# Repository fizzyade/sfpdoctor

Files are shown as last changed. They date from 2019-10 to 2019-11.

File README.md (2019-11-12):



[uri_license]: https://www.gnu.org/licenses/gpl-3.0.en.html
[uri_license_image]: https://img.shields.io/badge/License-GPLv3-blue.svg

[][uri_license]

# SFP Doctor
SFP Doctor is an open source hardware &amp; software project for reading and writing the EEPROM inside SFP &amp; SFP+ modules.

## About

SFP modules contain an EEPROM which contains information about the module.  This information includes the OUI (Organizationally Unique Identifier) which identifies the vendor of the module.

Some NIC's and switches are locked to using a particular vendors own SFP modules, this hardware and software project provides a tool for reading and modifying this information (providing the vendor has not disabled write access to the EEPROM).

The hardware design is intended to be as simple and cheap as possible, therefore it makes use of the [Cypress CYC8CKIT-059](https://www.cypress.com/documentation/development-kitsboards/cy8ckit-059-psoc-5lp-prototyping-kit-onboard-programmer-and) prototyping board as the USB interface to the EEPROM on the module, this board is readily and cheaply available.

## Repository Contents

* **/hardware** - [KiCad](http://kicad-pcb.org/) schematic and PCB layout source files.
* **/firmware** - The firmware for the [CY8C5888LTI-LP097](https://www.cypress.com/part/cy8c5888lti-lp097) microcontroller on the [Cypress CYC8CKIT-059](https://www.cypress.com/documentation/development-kitsboards/cy8ckit-059-psoc-5lp-prototyping-kit-onboard-programmer-and) prototyping board.
* **/software** - The desktop software to control the hardware.
* **/drivers** - Platform dependent drivers for the hardware interface.

Development takes place in the develop branch, master is currently a placeholder and not up to date.

## Required Tools

* **[Cypress PSoC Creator](https://www.cypress.com/products/psoc-creator-integrated-design-environment-ide)** for firmware development.
* **[KiCad](http://kicad-pcb.org/)** for hardware design.
* **[Node.js](https://nodejs.org/)** for desktop software.
* **[Yarn](https://yarnpkg.com/)** for desktop software.
* **[ELECTRON](https://electronjs.org/)** for desktop software development.

## Building Software

### Desktop

After installing the prequestite packages, use the following commands.

    yarn run build
    yarn run start

The platform binary can be created with the following commands.

    yarn run build
    yarn run dist

(*Please note that currently the software is not functional*)

### Firmware

Open the firmware project in PSOC Creator and select build to create the firmware image.

## Project Status

### Hardware

* **Design:** Complete.
* **Manufacture:** Complete.
    * _**07 Nov 2019**_ - Board Assembled, ready for test.
    * _**10 Nov 2019**_ - Board tested and working.

Bare BoardComplete Board

(_please **NOTE:** in this picture the CY8CKIT-059 module is installed the wrong way around, picture to be updated soon.)_

Render Rev. 1.3

(_Render of Rev. 1.3 board_)

### Firmware

* **Development:** Started.

### Software

* **Development:** Started.

## With Thanks

This project is using a USB VID & PID kindly allocated by [pid.codes](http://pid.codes).  Their repository can be found [here](https://github.com/pidcodes/pidcodes.github.com).  They support open source development by providing VID/PID pairs for free.

## License

This project is open source and the entire project is released under the [GPLv3 license](https://www.gnu.org/licenses/gpl-3.0.en.html).

Distributed as-is; no warranty is given.

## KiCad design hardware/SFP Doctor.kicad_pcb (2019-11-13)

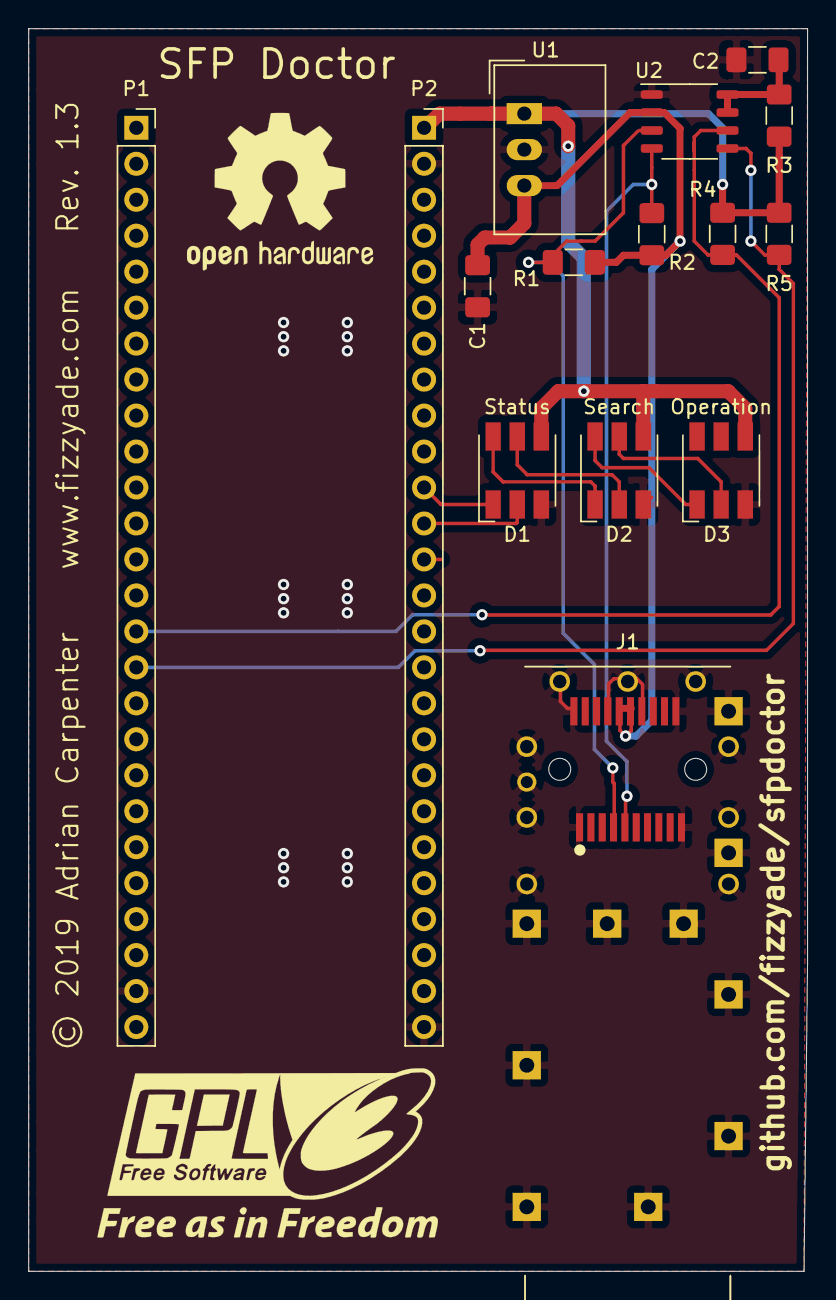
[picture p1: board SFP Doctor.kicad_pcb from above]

Board: 2 copper layers, 55.0 x 87.8 mm, 15 parts (0 on the bottom side), 14 nets.

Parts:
C1, C2: 100nF; C_1206_3216Metric_Pad1.42x1.75mm_HandSolder
D1, D2, D3: APA102; LED_RGB_5050-6
J1: 2227023-1; TE_2227023-1
P1, P2: CONN_01X26; PinSocket_1x26_P2.54mm_Vertical
R1, R2, R4, R5: 4K7; R_1206_3216Metric_Pad1.42x1.75mm_HandSolder
R3: 200K; R_1206_3216Metric_Pad1.42x1.75mm_HandSolder
U1: TSR_1-2433; Converter_DCDC_TRACO_TSR-1_THT
U2: PCA9306; SSOP-8_3.9x5.05mm_P1.27mm

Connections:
+3V3: C1.1, J1.15, J1.16, R1.1, R2.1, U1.3, U2.2
+5V: D1.4, D2.4, D3.4, P2.1, R3.1, R4.1, R5.1, U1.1
GND: C1.2, C2.2, D1.3, D2.3, D3.3, J1.1, J1.10, J1.11, J1.14, J1.17, J1.20, J1.S1, J1.S2, J1.S3, J1.S4, J1.S5, J1.S6, J1.S7, J1.S8, J1.S9, J1.S10, J1.S11, J1.S12, J1.S13, J1.S14, J1.S15, J1.S16, J1.S17, J1.S18, J1.S19, J1.S20, P1.25, P2.2, P2.26, U1.2, U2.1
LED_CLOCK: D1.2, P2.12
LED_DATA: D1.1, P2.11
unnamed: C2.1, R3.2, U2.7, U2.8
unnamed: D1.5, D2.2
unnamed: D1.6, D2.1
unnamed: D2.5, D3.2
unnamed: D2.6, D3.1
SCL_3V3: J1.5, R2.2, U2.4
SCL_5V: P1.16, R5.2, U2.5
SDA_3V3: J1.4, R1.2, U2.3
SDA_5V: P1.15, R4.2, U2.6

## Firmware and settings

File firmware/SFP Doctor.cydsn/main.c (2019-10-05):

/*
 * Copyright (C) 2019 Adrian Carpenter
 *
 * This file is part of SFP Doctor (https://github.com/fizzyade/sfpdoctor) 
 * a hardware & software project for reading/writing SFP/SFP+ modules.
 * 
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
 * You should have received a copy of the GNU General Public License
 * along with this program.  If not, see <http://www.gnu.org/licenses/>.
 */

#include <project.h>

/* USB device number. */
#define USBFS_DEVICE  (0u)

/* Active endpoints of USB device. */
#define IN_EP_NUM     (1u)
#define OUT_EP_NUM    (2u)

/* Size of SRAM buffer to store endpoint data. */
#define BUFFER_SIZE   (64u)

#if (USBFS_16BITS_EP_ACCESS_ENABLE)
    /* To use the 16-bit APIs, the buffer has to be:
    *  1. The buffer size must be multiple of 2 (when endpoint size is odd).
    *     For example: the endpoint size is 63, the buffer size must be 64.
    *  2. The buffer has to be aligned to 2 bytes boundary to not cause exception
    *     while 16-bit access.
    */
    #ifdef CY_ALIGN
        /* Compiler supports alignment attribute: __ARMCC_VERSION and __GNUC__ */
        CY_ALIGN(2) uint8 buffer[BUFFER_SIZE];
    #else
        /* Complier uses pragma for alignment: __ICCARM__ */
        #pragma data_alignment = 2
        uint8 buffer[BUFFER_SIZE];
    #endif /* (CY_ALIGN) */
#else
    /* There are no specific requirements to the buffer size and alignment for 
    * the 8-bit APIs usage.
    */
    uint8 buffer[BUFFER_SIZE];
#endif /* (USBFS_GEN_16BITS_EP_ACCESS) */


/*
 *
 */

int main()
{
    uint16 length;

    CyGlobalIntEnable;

    /* Start USBFS operation with 5V operation. */
    USBFS_Start(USBFS_DEVICE, USBFS_5V_OPERATION);

    /* Wait until device is enumerated by host. */
    while (0u == USBFS_GetConfiguration())
    {
    }

    /* Enable OUT endpoint to receive data from host. */
    USBFS_EnableOutEP(OUT_EP_NUM);

    for(;;)
    {
        /* Check if configuration is changed. */
        if (0u != USBFS_IsConfigurationChanged())
        {
            /* Re-enable endpoint when device is configured. */
            if (0u != USBFS_GetConfiguration())
            {
                /* Enable OUT endpoint to receive data from host. */
                USBFS_EnableOutEP(OUT_EP_NUM);
            }
        }

        /* Check if data was received. */
        if (USBFS_OUT_BUFFER_FULL == USBFS_GetEPState(OUT_EP_NUM))
        {
            /* Read number of received data bytes. */
            length = USBFS_GetEPCount(OUT_EP_NUM);

            /* Trigger DMA to copy data from OUT endpoint buffer. */
        #if (USBFS_16BITS_EP_ACCESS_ENABLE)
            USBFS_ReadOutEP16(OUT_EP_NUM, buffer, length);
        #else
            USBFS_ReadOutEP(OUT_EP_NUM, buffer, length);
        #endif /* (USBFS_GEN_16BITS_EP_ACCESS) */

            /* Wait until DMA completes copying data from OUT endpoint buffer. */
            while (USBFS_OUT_BUFFER_FULL == USBFS_GetEPState(OUT_EP_NUM))
            {
            }
            
            /* Enable OUT endpoint to receive data from host. */
            USBFS_EnableOutEP(OUT_EP_NUM);

            /* Wait until IN buffer becomes empty (host has read data). */
            while (USBFS_IN_BUFFER_EMPTY != USBFS_GetEPState(IN_EP_NUM))
            {
            }

        /* Trigger DMA to copy data into IN endpoint buffer.
        * After data has been copied, IN endpoint is ready to be read by the
        * host.
        */
        #if (USBFS_16BITS_EP_ACCESS_ENABLE)
            USBFS_LoadInEP16(IN_EP_NUM, buffer, length);
        #else
            USBFS_LoadInEP(IN_EP_NUM, buffer, length);
        #endif /* (USBFS_GEN_16BITS_EP_ACCESS) */
        }
    }
}


/* [] END OF FILE */

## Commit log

2019-09-26 repo: initial commit
    [SFP Doctor.kicad_pcb, SFP Doctor.sch]
2019-09-27 chore(package): Added Windows device driver binaries
2019-10-04 wip: changes for USB
    - VID/PID allocated by pid.codes
    - Driver .inf modified for new VID/PID
    - Firmware modified for new VID/PID
    - Added Windows PowerShell script to create code signing certificate
    - Added Windows PowerShell script for generating driver .cat file and signing the driver
    - README.md modified to include links to pid.codes
2019-10-06 chore: switched project to using yarn
2019-11-08 chore: updated schematic
    Missing capacitor values added
    Logos added to schematic
    [SFP Doctor.sch]
2019-11-08 repo: updated README.md
    Added photographs of assembled boards.
2019-11-10 chore(hardware): added pin labels
    added pin labels to the CYC8CKIT-059 symbol
    [SFP Doctor.sch]
2019-11-11 wip: revision 1.2 of PCB
    [SFP Doctor.kicad_pcb, SFP Doctor.sch]
2019-11-11 wip: revision 1.3 of PCB
    Moved SFP cage
    [SFP Doctor.kicad_pcb, SFP Doctor.sch]

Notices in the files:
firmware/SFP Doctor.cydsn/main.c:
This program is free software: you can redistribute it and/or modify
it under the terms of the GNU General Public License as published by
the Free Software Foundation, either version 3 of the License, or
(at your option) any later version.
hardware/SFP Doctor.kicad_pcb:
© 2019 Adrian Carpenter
